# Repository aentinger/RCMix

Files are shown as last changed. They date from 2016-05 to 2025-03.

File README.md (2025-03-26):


💾 RC Mixer
===========

The LXRobotics P20 RC Mixer is a device which can mix up to 4 standard RC PWM inputs (pulse period 20 ms, pulse duration 1-2 ms) to up to 6 standard RC PWM outputs applying any used definable control algorithm.

# 📸 Image

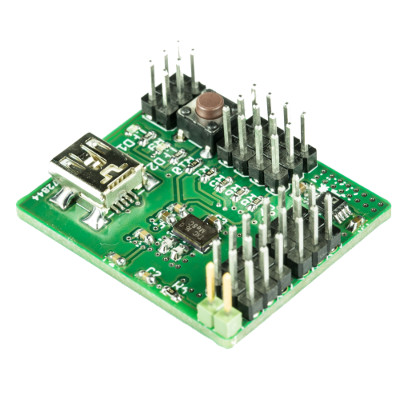
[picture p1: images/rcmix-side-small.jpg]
LXRobotics P12 Relay Shield


## 💻 Installation

* Install the Arduino IDE

```
sudo apt-get install arduino
```
* Clone this repository

```
git clone https://github.com/aentinger/rcmix
```

## 💻 Building

* Open project in Arduino IDE by left clicking on `rcmixarduino.ino`

* Select ATMega32U4 MCU via the menu `Tools - Board - Arduino Leonardo`

* Compile with `Ctrl+R`

## 💻 Upload

* Connect an **AVR ISP mkII** with the rcmix hardware
 
* After successful compilation of the Arduino sketch select `Tools - Programmer - AVRISP mkII`
 
* Upload with `Ctrl+U`

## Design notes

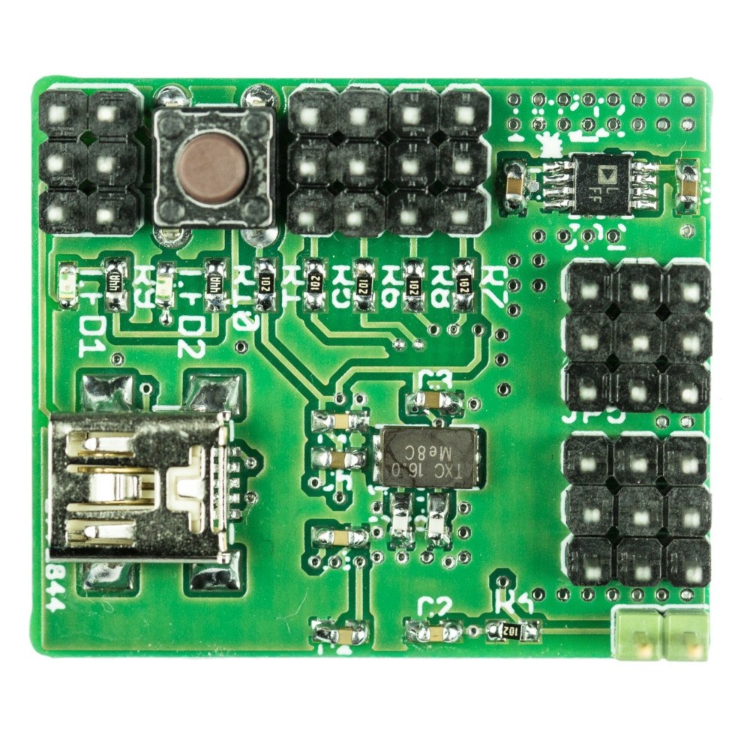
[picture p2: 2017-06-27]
images/rcmix-top-large.jpg

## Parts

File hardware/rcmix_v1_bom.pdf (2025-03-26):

Menge | Schaltplan | Bezeichnung | Farnell | Preis (1 Stück) | Gesamtpreis | Wird bestückt | Footprint | Säckchen
1 | IC1 | ATMEGA32U4, TQFP | 2443182 | € 6,42 | € 6,42 | X
1 | JP1 | Stiftleiste, 1 x 2, 2.54 mm | 3418285 | € 0,37 | € 0,37
10 | JP2-JP11 | Stiftleiste, 1 x 3, 2.54 mm | 1022249 | € 0,08 | € 0,83
6 | R1,R4-R8 | 1k, 0603 | 2333561 | € 0,02 | € 0,09 | X
2 | R2,R3 | 22R, 0603 | 2331979 | € 0,01 | € 0,03 | X
4 | C1,C2,C4,C6 | 100 nF, 0603 | 9406140 | € 0,09 | € 0,35 | X
4 | C3,C5,C7,C8 | 1 µF, 0603 | 1759408 | € 0,01 | € 0,05 | X
1 | IC2 | LDO-Regler, 5 V, 0.2 V, 500 mA, MSOP8 | 2074873 | € 2,53 | € 2,53 | X
1 | Y1 | Quarz, 16 MHz, 18 pF, SMD | 2413989 | € 0,90 | € 0,90 | X
2 | C9,C10 | 18 pF, 0603 | 1759056 | € 0,01 | € 0,02 | X
1 | JP12 | USB-Buchse, Female, Mini-B | | | € - | X | 0
1 | JP13 | Stiftleiste, 2x3, 2.54 mm | 1022226 | € 0,27 | € 0,27
1 | S1 | Taster, THT, 5 mm | 9471707 | € 0,13 | € 0,13
1 | LED1 | LED, 0603, Vf=2,05V, If=10 mA, Grün | 1699415 | € 0,32 | € 0,32 | X
1 | LED2 | LED, 0603, Vf=2,05V, If=10 mA, Bernstein | 1908046 | € 0,24 | € 0,24 | X
2 | R9,R10 | 280R, 0603 | 1170731 | € 0,02 | € 0,03 | X
Summe | € | 12,58

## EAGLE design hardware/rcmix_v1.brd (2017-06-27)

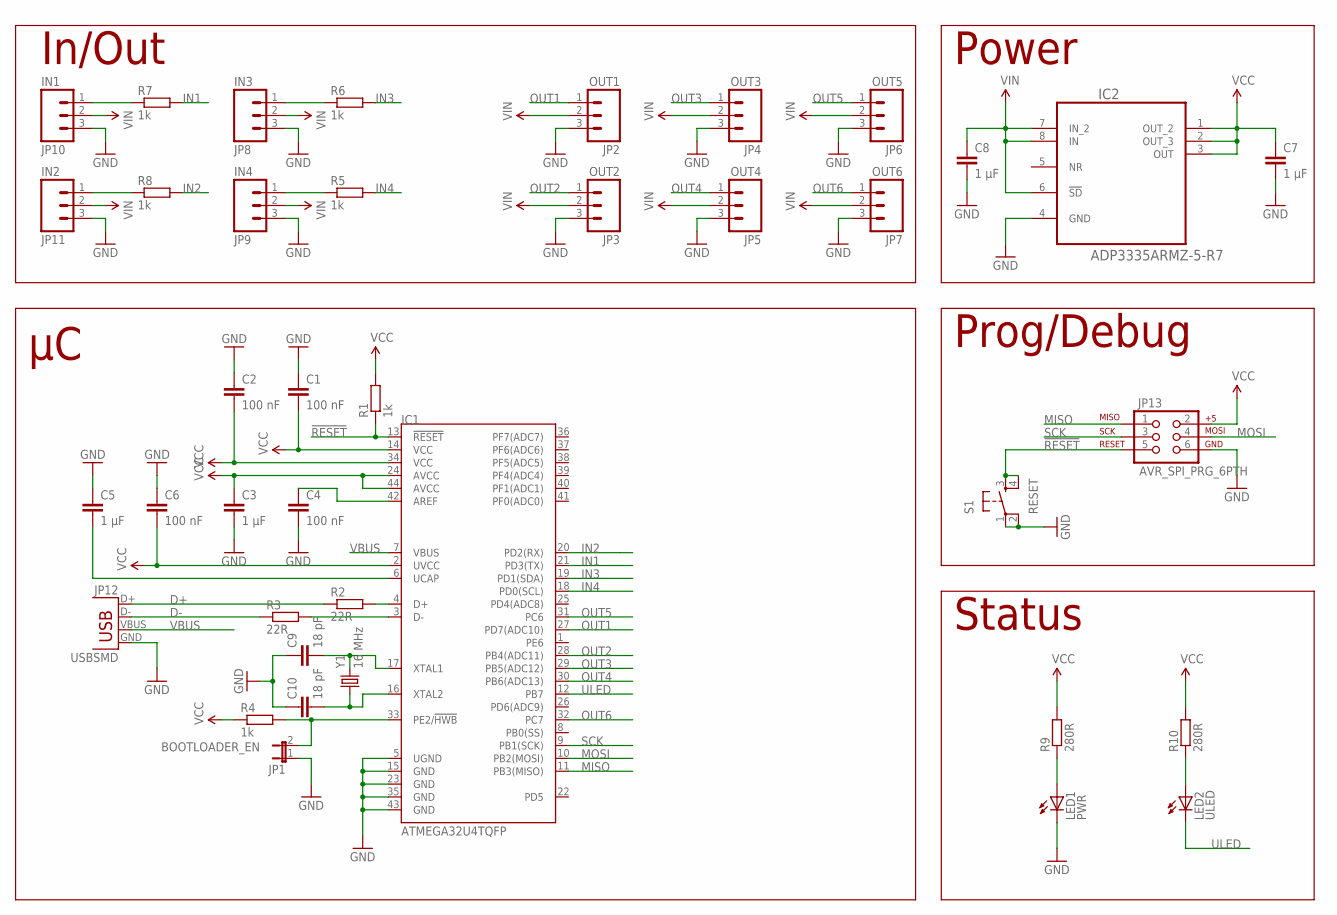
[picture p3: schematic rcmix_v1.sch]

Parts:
C1, C2, C4, C6: 100 nF; C0603K
C3, C5, C7, C8: 1 µF; C0603K
C9, C10: 18 pF; C0603K
IC1: ATMEGA32U4TQFP; SPARKFUN-DIGITALIC_TQFP44
IC2: ADP3335ARMZ-5-R7; SOP65P490X110-8N
JP1: BOOTLOADER_EN; JP1
JP2: OUT1; 1X03
JP3: OUT2; 1X03
JP4: OUT3; 1X03
JP5: OUT4; 1X03
JP6: OUT5; 1X03
JP7: OUT6; 1X03
JP8: IN3; 1X03
JP9: IN4; 1X03
JP10: IN1; 1X03
JP11: IN2; 1X03
JP12: USBSMD; USB-MINIB
JP13: AVR_SPI_PRG_6PTH; 2X3
LED1: PWR; CHIP-LED0603
LED2: ULED; CHIP-LED0603
R1, R4, R5, R6, R7, R8: 1k; R0603
R2, R3: 22R; R0603
R9, R10: 280R; R0603
S1: RESET; TACTILE-PTH
Y1: 16 MHz; CRYSTAL-TXC-7A

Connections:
!RESET: IC1.13 (!RESET), JP13.5, R1.1, S1.3, S1.4
D+: JP12.D+, R2.1
D-: JP12.D-, R3.1
GND: C1.1, C2.1, C3.2, C4.2, C5.1, C6.1, C7.2, C8.2, C9.1, C10.1, IC1.5 (UGND), IC1.15 (GND), IC1.23 (GND), IC1.35 (GND), IC1.43 (GND), IC2.4 (GND), JP1.1, JP2.3, JP3.3, JP4.3, JP5.3, JP6.3, JP7.3, JP8.3, JP9.3, JP10.3, JP11.3, JP12.GND, JP13.6, LED1.C, S1.1, S1.2
IN1: IC1.21 (PD3(TX)), R7.2
IN2: IC1.20 (PD2(RX)), R8.2
IN3: IC1.19 (PD1(SDA)), R6.2
IN4: IC1.18 (PD0(SCL)), R5.2
MISO: IC1.11 (PB3(MISO)), JP13.1
MOSI: IC1.10 (PB2(MOSI)), JP13.4
unnamed: IC1.4 (D+), R2.2
unnamed: IC1.3 (D-), R3.2
unnamed: C4.1, IC1.42 (AREF)
unnamed: C5.2, IC1.6 (UCAP)
unnamed: IC1.33 (PE2/!HWB), JP1.2, R4.2
unnamed: JP10.1, R7.1
unnamed: JP11.1, R8.1
unnamed: JP8.1, R6.1
unnamed: JP9.1, R5.1
unnamed: C9.2, IC1.17 (XTAL1), Y1.P$2 (2)
unnamed: LED1.A, R9.1
unnamed: C10.2, IC1.16 (XTAL2), Y1.P$1 (1)
unnamed: LED2.A, R10.1
OUT1: IC1.27 (PD7(ADC10)), JP2.1
OUT2: IC1.28 (PB4(ADC11)), JP3.1
OUT3: IC1.29 (PB5(ADC12)), JP4.1
OUT4: IC1.30 (PB6(ADC13)), JP5.1
OUT5: IC1.31 (PC6), JP6.1
OUT6: IC1.32 (PC7), JP7.1
SCK: IC1.9 (PB1(SCK)), JP13.3
ULED: IC1.12 (PB7), LED2.C
VBUS: IC1.7 (VBUS), JP12.VBUS
VCC: C1.2, C2.2, C3.1, C6.2, C7.1, IC1.2 (UVCC), IC1.14 (VCC), IC1.24 (AVCC), IC1.34 (VCC), IC1.44 (AVCC), IC2.1 (OUT_2), IC2.2 (OUT_3), IC2.3 (OUT), JP13.2, R1.2, R4.1, R9.2, R10.2
VIN: C8.1, IC2.6 (!SD), IC2.7 (IN_2), IC2.8 (IN), JP2.2, JP3.2, JP4.2, JP5.2, JP6.2, JP7.2, JP8.2, JP9.2, JP10.2, JP11.2

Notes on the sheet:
In/Out
Power
Prog/Debug
Status

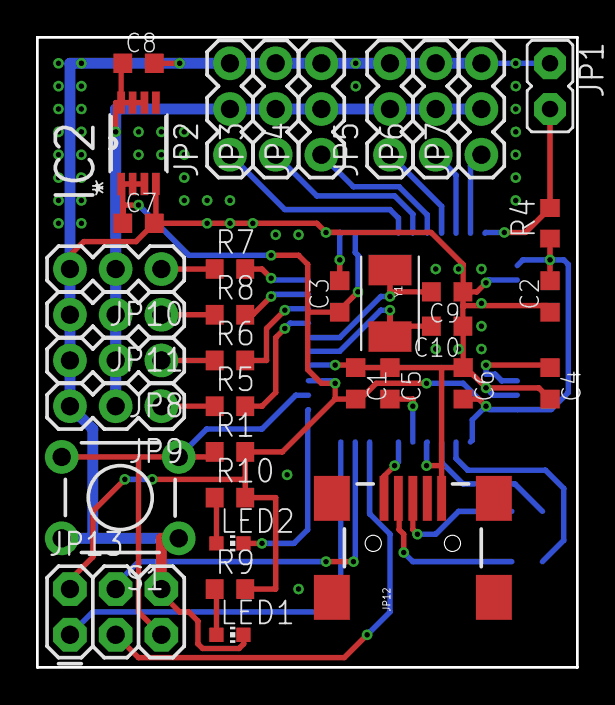
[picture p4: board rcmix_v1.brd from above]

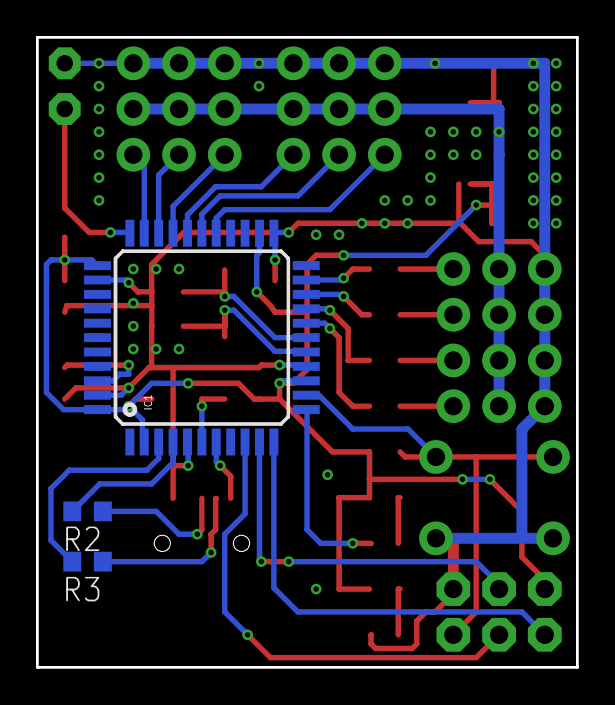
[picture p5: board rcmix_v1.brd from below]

Board: 2 copper layers, 30.0 x 35.0 mm, 39 parts (3 on the bottom side), 34 nets.

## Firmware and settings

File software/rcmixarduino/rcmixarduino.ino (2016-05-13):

/*
 * MIT License
 *
 * Copyright (c) 2016 LXRobotics GmbH / Alexander Entinger, MSc
 *
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
 * THE SOFTWARE IS PROVIDED "AS IS", WITHOUT WARRANTY OF ANY KIND, EXPRESS OR
 * IMPLIED, INCLUDING BUT NOT LIMITED TO THE WARRANTIES OF MERCHANTABILITY,
 * FITNESS FOR A PARTICULAR PURPOSE AND NONINFRINGEMENT. IN NO EVENT SHALL THE
 * AUTHORS OR COPYRIGHT HOLDERS BE LIABLE FOR ANY CLAIM, DAMAGES OR OTHER
 * LIABILITY, WHETHER IN AN ACTION OF CONTRACT, TORT OR OTHERWISE, ARISING FROM,
 * OUT OF OR IN CONNECTION WITH THE SOFTWARE OR THE USE OR OTHER DEALINGS IN THE
 * SOFTWARE.
 */

/************************************************************************/
/* INCLUDES                                                             */
/************************************************************************/

#include <stdlib.h>

#include <avr/io.h>
#include <avr/interrupt.h>

#include <util/delay.h>

#include "led.h"
#include "rcin.h"
#include "rcout.h"
#include "control.h"

#include "config.h"

#if defined(CONFIG_USE_CONTROL_DEMO)
#include "control_demo.h"
#elif defined(CONFIG_USE_CONTROL_OMNIDRIVE_3_WHEELS)
#include "control_omnidrive_3_wheels.h"
#endif

/************************************************************************/
/* GLOBAL VARIABLES                                                     */
/************************************************************************/

Control control(
#if defined(CONFIG_USE_CONTROL_DEMO)
  &ControlDemo::isGoodFunc, 
  &ControlDemo::failsafeFunc, 
  &ControlDemo::mixingFunc, 
  &ControlDemo::transitionToFailsafeFunc, 
  &ControlDemo::transitionToMixingFunc
#elif defined(CONFIG_USE_CONTROL_OMNIDRIVE_3_WHEELS)
  ControlOmnidrive3Wheels::isGoodFunc, 
  ControlOmnidrive3Wheels::failsafeFunc, 
  ControlOmnidrive3Wheels::mixingFunc, 
  ControlOmnidrive3Wheels::transitionToFailsafeFunc, 
  ControlOmnidrive3Wheels::transitionToMixingFunc
#endif
  );

/************************************************************************/
/* ARDUINO FUNCTIONS                                                    */
/************************************************************************/

void setup()
{
  Led::begin();
  RcIn::begin();
  RcOut::begin();
}

void loop()
{
  control.execute();
}

/************************************************************************/
/* INTERRUPTS                                                           */
/************************************************************************/

/** 
 * \brief this interrupt is executed when a interrupt is triggered
 * for which no isr was installed - signal a failure in that case.
 */
ISR(BADISR_vect)
{
	for(;;)
	{
		_delay_ms(50);
		Led::setState(LED_ON);
		_delay_ms(50);
		Led::setState(LED_OFF);
	}
}

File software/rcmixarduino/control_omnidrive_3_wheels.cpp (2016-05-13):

/*
 * MIT License
 *
 * Copyright (c) 2016 LXRobotics GmbH / Alexander Entinger, MSc
 *
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
 * THE SOFTWARE IS PROVIDED "AS IS", WITHOUT WARRANTY OF ANY KIND, EXPRESS OR
 * IMPLIED, INCLUDING BUT NOT LIMITED TO THE WARRANTIES OF MERCHANTABILITY,
 * FITNESS FOR A PARTICULAR PURPOSE AND NONINFRINGEMENT. IN NO EVENT SHALL THE
 * AUTHORS OR COPYRIGHT HOLDERS BE LIABLE FOR ANY CLAIM, DAMAGES OR OTHER
 * LIABILITY, WHETHER IN AN ACTION OF CONTRACT, TORT OR OTHERWISE, ARISING FROM,
 * OUT OF OR IN CONNECTION WITH THE SOFTWARE OR THE USE OR OTHER DEALINGS IN THE
 * SOFTWARE.
 */

/************************************************************************/
/* INCLUDES                                                             */
/************************************************************************/

#include "control_omnidrive_3_wheels.h"

#include <math.h>

#include "rcin.h"
#include "rcout.h"

#ifdef CONFIG_USE_CONTROL_OMNIDRIVE_3_WHEELS

/************************************************************************/
/* CONSTANTS                                                            */
/************************************************************************/

static uint16_t const CENTER_VALUE_PULSE_WIDTH_US = 1500;

/************************************************************************/
/* PUBLIC FUNCTIONS	                                                    */
/************************************************************************/

/** 
 * \brief this function returns true when all signals used in this specific mixer are good
 */
bool ControlOmnidrive3Wheels::isGoodFunc()
{
  return (RcIn::isGood(IN1) && RcIn::isGood(IN2) && RcIn::isGood(IN3));
}

/** 
 * \brief this function implements the failsafe behaviour of this specific mixer
 */
void ControlOmnidrive3Wheels::failsafeFunc()
{
  /* Nothing to do here, outputs are turned off in the
   * transition to failsafe
   */
}

/** 
 * \brief this function implements the mixing behavior (function fOUT(IN1, IN2, ...) of this specific mixer
 */
void ControlOmnidrive3Wheels::mixingFunc()
{
  /* IN1
   *  IN1 > 1500 -> FWD
   *  IN1 < 1500 -> BWD
   * IN2
   *  IN2 > 1500 -> RIGHT
   *  IN2 < 1500 -> LEFT
   * IN3
   *  IN3 > 1500 -> ROTATE CLOCKWISE
   *  IN3 < 1500 -> ROTATE COUNTER CLOCKWISE
   */

  uint16_t const fwd_bwd = RcIn::getPulseDurationUs(IN1);
  uint16_t const left_right = RcIn::getPulseDurationUs(IN2);
  uint16_t const rotate = RcIn::getPulseDurationUs(IN3);

  bool const do_move = !isStickInCenterPosition(fwd_bwd, DEADZONE_US)
      || !isStickInCenterPosition(left_right, DEADZONE_US);
  bool const do_rotate = !isStickInCenterPosition(rotate, DEADZONE_US);

  /* OUT1 = MOTOR A
   * OUT2 = MOTOR B
   * OUT3 = MOTOR C
   */

  if (do_move)
  {
    ControlOmnidrive3Wheels::doMove(fwd_bwd, left_right);
  }
  else if (do_rotate)
  {
    ControlOmnidrive3Wheels::doRotate(rotate);
  }
  else
  {
    ControlOmnidrive3Wheels::doNothing();
  }
}

/** 
 * \brief this function implements the behaviour if a transition from mixing to failsafe is taking place
 */
void ControlOmnidrive3Wheels::transitionToFailsafeFunc()
{
  RcOut::setRcOutState(OUT1, OUTx_OFF);
  RcOut::setRcOutState(OUT2, OUTx_OFF);
  RcOut::setRcOutState(OUT3, OUTx_OFF);
}

/** 
 * \brief this function implements the behaviour if a transition from failsafe to mixing is taking place
 */
void ControlOmnidrive3Wheels::transitionToMixingFunc()
{
  RcOut::setRcOutState(OUT1, OUTx_ON);
  RcOut::setRcOutState(OUT2, OUTx_ON);
  RcOut::setRcOutState(OUT3, OUTx_ON);
}

/************************************************************************/
/* PRIVATE FUNCTIONS	                                                */
/************************************************************************/

/** 
 * \brief returns true if 1500 - deadzone_us <= pulse_duration_us <= 1500 + deadzone_us
 */
bool ControlOmnidrive3Wheels::isStickInCenterPosition(uint16_t const pulse_duration_us, uint16_t const deadzone_us)
{
  uint16_t const min_value_for_stick_in_center = CENTER_VALUE_PULSE_WIDTH_US - deadzone_us;
  uint16_t const max_value_for_stick_in_center = CENTER_VALUE_PULSE_WIDTH_US + deadzone_us;

  bool const is_stick_in_center_position = (pulse_duration_us >= min_value_for_stick_in_center)
      && (pulse_duration_us <= max_value_for_stick_in_center);

  return is_stick_in_center_position;
}

/** 
 * \brief this function controls the moving of the omnidirectional platform
 */
void ControlOmnidrive3Wheels::doMove(uint16_t const fwd_bwd, uint16_t const left_right)
{
  /* http://physics.stackexchange.com/questions/57401/omni-directional-motion-resolving-three-or-more-vectors */

  float const fx = (float) ((int16_t) (left_right) - (int16_t) (CENTER_VALUE_PULSE_WIDTH_US));
  float const fy = (float) ((int16_t) (fwd_bwd) - (int16_t) (CENTER_VALUE_PULSE_WIDTH_US));

  static float const C1 = 2.0 / 3.0;
  static float const C2 = -1.0 / 3.0;
  static float const C3 = -1.0 / sqrt(3.0);

  float const fa = fx * C1;
  float const fb = fx * C2 + fy * C3;
  float const fc = fx * C2 - fy * C3;

  uint16_t const motor_A = (uint16_t) ((int16_t) (fa) + (int16_t) (CENTER_VALUE_PULSE_WIDTH_US));
  uint16_t const motor_B = (uint16_t) ((int16_t) (fb) + (int16_t) (CENTER_VALUE_PULSE_WIDTH_US));
  uint16_t const motor_C = (uint16_t) ((int16_t) (fc) + (int16_t) (CENTER_VALUE_PULSE_WIDTH_US));

  ControlOmnidrive3Wheels::setMotorA(motor_A);
  ControlOmnidrive3Wheels::setMotorB(motor_B);
  ControlOmnidrive3Wheels::setMotorC(motor_C);
}

/** 
 * \brief this function controls the rotation of the omnidirectional platform
 */
void ControlOmnidrive3Wheels::doRotate(uint16_t const rotate)
{
  ControlOmnidrive3Wheels::setMotorA(rotate);
  ControlOmnidrive3Wheels::setMotorB(rotate);
  ControlOmnidrive3Wheels::setMotorC(rotate);
}

/** 
 * \brief absolutely do nothing - all outputs are at 1500 (neutral value)
 */
void ControlOmnidrive3Wheels::doNothing()
{
  ControlOmnidrive3Wheels::setMotorA(CENTER_VALUE_PULSE_WIDTH_US);
  ControlOmnidrive3Wheels::setMotorB(CENTER_VALUE_PULSE_WIDTH_US);
  ControlOmnidrive3Wheels::setMotorC(CENTER_VALUE_PULSE_WIDTH_US);
}

/** 
 * \brief control the three motors
 */
void ControlOmnidrive3Wheels::setMotorA(uint16_t const pulse_duration_us)
{
  RcOut::setPwmPulseDurationUs(OUT1, pulse_duration_us);
}

void ControlOmnidrive3Wheels::setMotorB(uint16_t const pulse_duration_us)
{
  RcOut::setPwmPulseDurationUs(OUT2, pulse_duration_us);
}

void ControlOmnidrive3Wheels::setMotorC(uint16_t const pulse_duration_us)
{
  RcOut::setPwmPulseDurationUs(OUT3, pulse_duration_us);
}

#endif

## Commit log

2016-01-08 Bugfix in functionality for transitioning between failsafe and mixing state
    [control_demo.cpp]
2016-05-13 Transforming atmel studio code to arduino code
2017-06-27 Adding hardware + images
    [rcmix_v1.brd, rcmix_v1.sch]
2025-03-26 Add BOM.

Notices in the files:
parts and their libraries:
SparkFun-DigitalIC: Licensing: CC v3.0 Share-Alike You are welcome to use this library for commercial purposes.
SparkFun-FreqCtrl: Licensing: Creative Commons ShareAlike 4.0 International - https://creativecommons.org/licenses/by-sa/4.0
